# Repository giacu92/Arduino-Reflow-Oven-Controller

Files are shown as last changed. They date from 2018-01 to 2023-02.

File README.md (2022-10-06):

# GFE-Reflow-Oven-Controller v2
This repo contains all the files of my Arduino Zero (samd21) based Reflow Oven PID Controller for reflow smd soldering.

* Author: Giacomo Mammarella
* email: giacu92@gmail.com,

New

[Check the live version!](https://a360.co/3yNSDE0)

# For Arduino Nano (V1.1) refer to appropriate branch --> [v1.1](https://github.com/giacu92/Arduino-Reflow-Oven-Controller/tree/v1.1)

# File list:
* [Arduino files](https://github.com/giacu92/Reflow-Oven-Controller/tree/master/GFE_Reflow_Oven_Controller): The Arduino files source folder.
* [Processing file](https://github.com/giacu92/Reflow-Oven-Controller/tree/master/Processing/Reflow_oven_serial_controller): The Processing files source folder.
* [Prova.brd](https://github.com/giacu92/GFE-Reflow-Oven-Controller/blob/master/Prova.brd): Cadsoft Eagle 6.5 .brd file of my Reflow Oven Controller. 
* [Prova.sch](https://github.com/giacu92/GFE-Reflow-Oven-Controller/blob/master/Prova.sch): Cadsoft Eagle 6.5 .sch file of my Reflow Oven Controller.

# Mounting the board:
Get a fully assembled board [here](http://giacu92.bigcartel.com/product/reflow-oven-controller-board-v1-1) or etch it yourself. -- available soon

A newer version of the pcb featuring two thermocouple interface, +12V fan output (for cooling) is under development. It will fit the 16x2 LCD screen and mounts underneath it. Here's a sample rendering. Also a new pid autotuner function and MicroSD card interface for saving custom profiles are getting implemented.

New_top

This project is under continuous update (May 2022). Contact me for anything :)

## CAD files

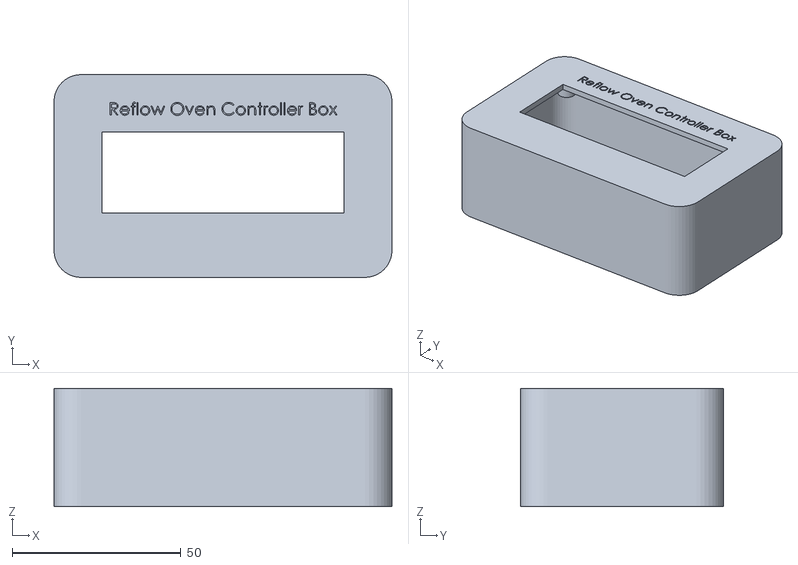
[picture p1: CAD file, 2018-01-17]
Serial Reflow Oven Controller Box.STL
100.0 x 60.0 x 35.0

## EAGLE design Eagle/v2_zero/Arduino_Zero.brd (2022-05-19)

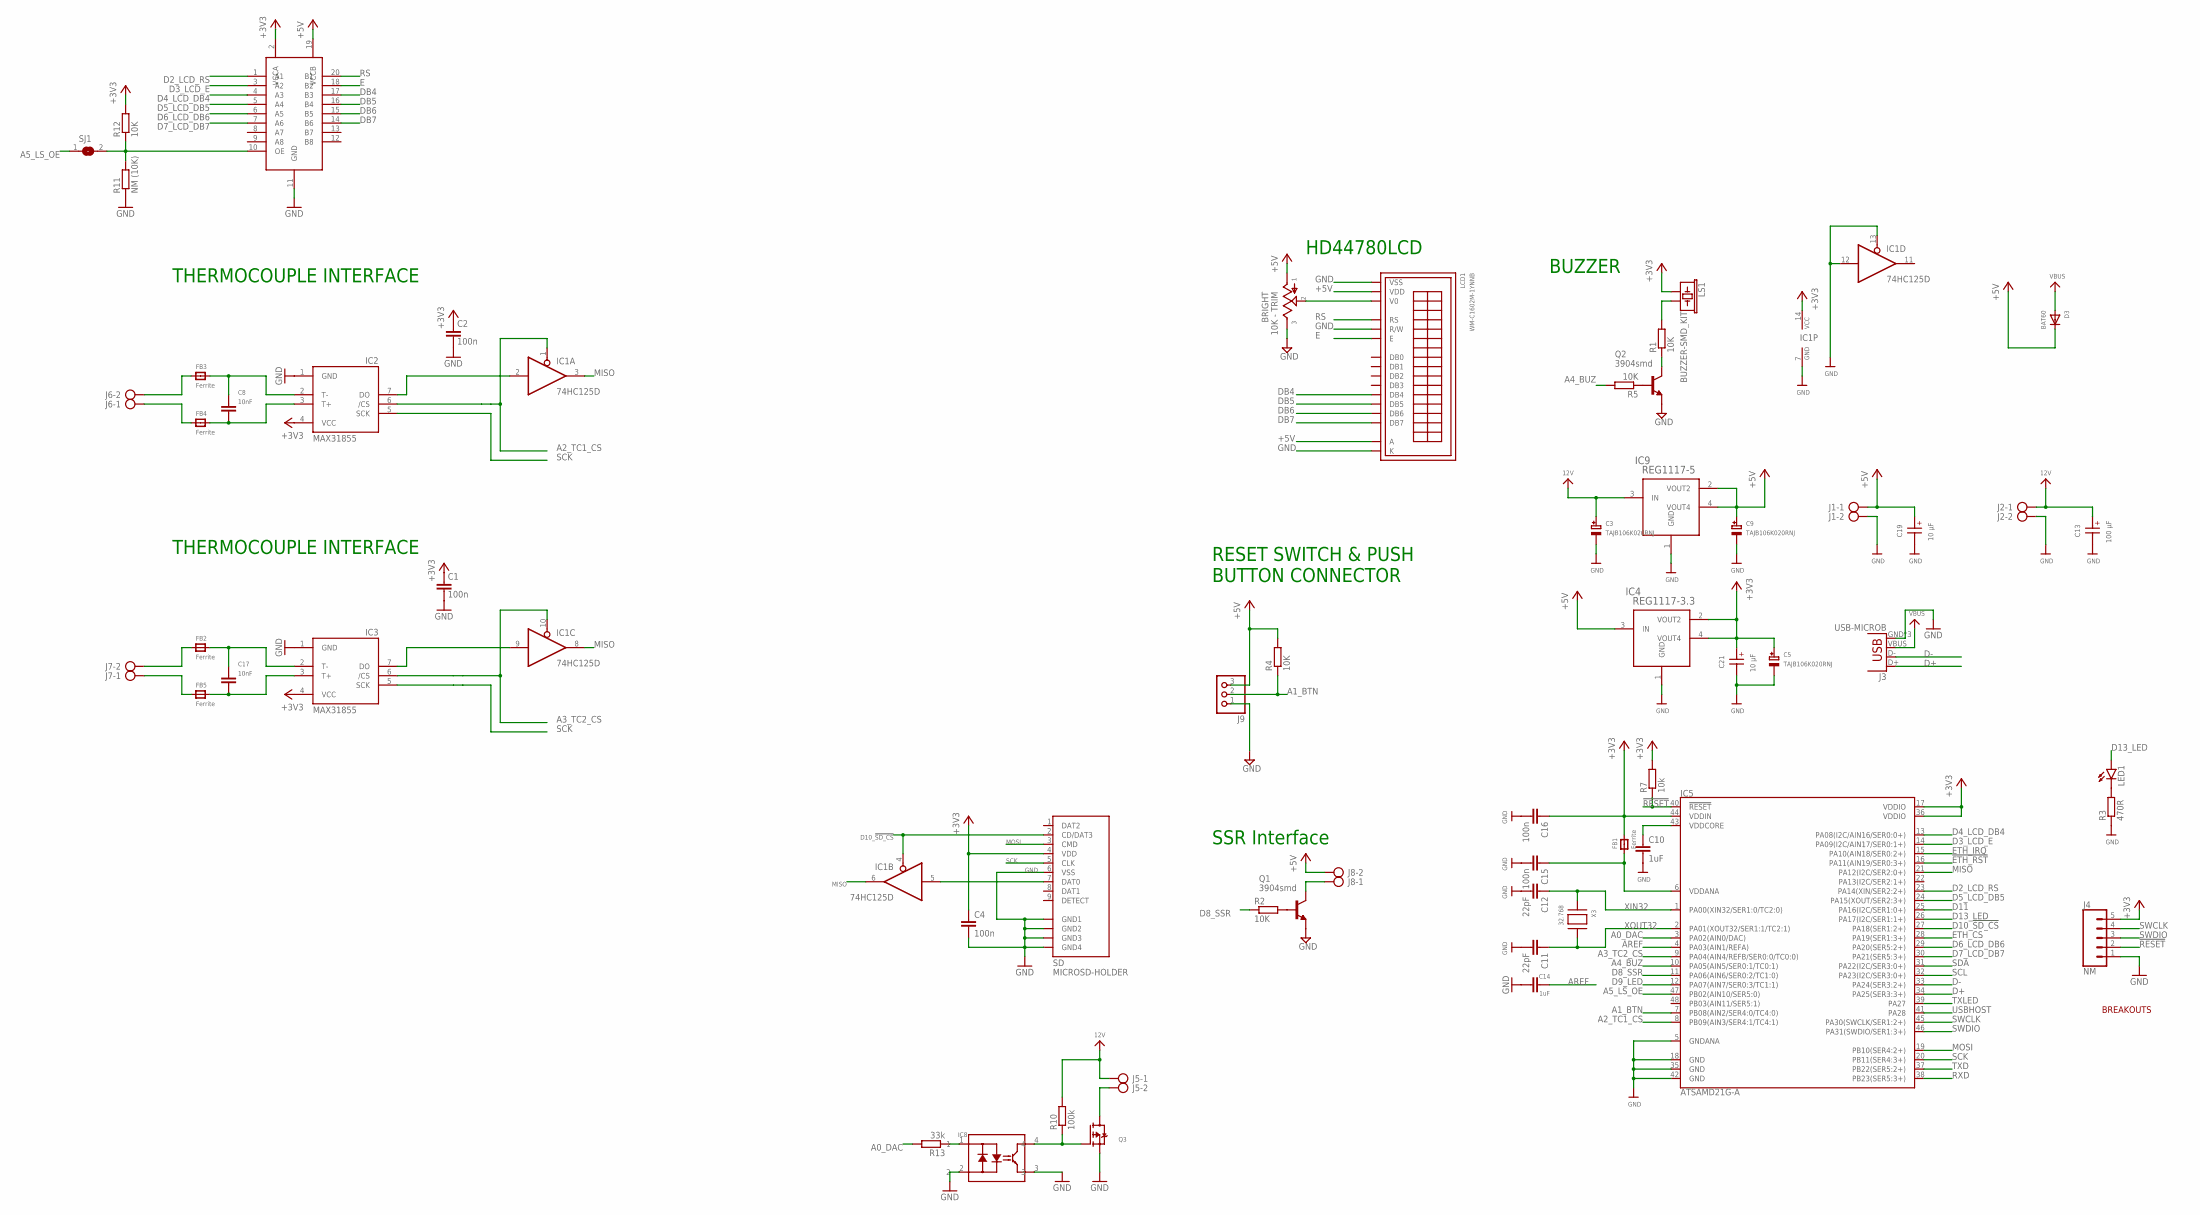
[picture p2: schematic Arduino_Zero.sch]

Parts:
BRIGHT: 10K - TRIM; B25P
C1, C2, C4, C15, C16: 100n; C0603K
C3, C5, C9: TAJB106K020RNJ; CAPMP3528X210N
C8, C17: 10nF; C0603K
C10, C14: 1uF; C0603K
C11, C12: 22pF; C0603K
C13: 100 µF; WCAP-ASLI_6.3X7.7(DXL)
C19, C21: 10 µF; WCAP-ASLI_4X5.5(DXL)
D3: BAT60; SOD323
FB1, FB2, FB3, FB4, FB5: Ferrite; BEADC3216X100N
IC1: 74HC125D; SO14
IC2, IC3: MAX31855; SO08
IC4: REG1117-3.3; DCY0004A_N
IC5: ATSAMD21G-A; TQFP-48
IC7: TXS0108E; TSSOP20
IC8: TLP283; SO4_TOS
IC9: REG1117-5; DCY0004A_N
J1, J2, J5, J6, J7, J8: AK500/2ASD; AK500/2
J3: USB-MICROB
J4: NM; 1X05_1.27MM
J9: PINHD-1X3; 1X03
LCD1: WM-C1602M-1YNNB; LCD_2
LED1: LEDCHIPLED_0805; CHIPLED_0805
LS1: BUZZER-SMD_KIT; BUZZER-CCV-KIT
Q1, Q2: 3904smd; SOT23-BEC
Q3: MOSFET-PWIDE; SOT23-WIDE
R1, R2, R4, R5, R12: 10K; R0603
R3: 470R; R0603
R7: 10k; R0603
R10: 100k; R0603
R11: NM (10K); R0603
R13: 33k; R0603
SD: MICROSD-HOLDER; MICROSD-HOLDER-ALIEX
SJ1: SJ
X3: 32.768; XTAL3215

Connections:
12V: C3.1 (+), C13.1 (+), IC9.3 (IN), J2.1, J5.1, R10.2
!ETH_RST: IC5.16 (PA11(AIN19/SER0:3+))
!RESET: IC5.40 (!RESET!), J4.2, R7.1
+3V3: C1.1, C2.1, C4.1, C5.1 (+), C16.1, C21.1 (+), FB1.2, IC1.14 (VCC), IC2.4 (VCC), IC3.4 (VCC), IC4.2 (VOUT2), IC4.4 (VOUT4), IC5.17 (VDDIO), IC5.36 (VDDIO), IC5.44 (VDDIN), IC7.2 (VCCA), J4.5, LS1.+ (1), R7.2, R12.2, SD.4 (VDD)
+5V: BRIGHT.1, C9.1 (+), C19.1 (+), D3.1 (C), IC4.3 (IN), IC7.19 (VCCB), IC9.2 (VOUT2), IC9.4 (VOUT4), J1.1, J8.2, J9.3, LCD1.2 (VDD), LCD1.15 (A), R4.2
A0_DAC: IC5.3 (PA02(AIN0/DAC)), R13.2
A1_BTN: IC5.7 (PB08(AIN2/SER4:0/TC4:0)), J9.2, R4.1
A2_TC1_CS: IC1.1 (OE), IC2.6 (/CS), IC5.8 (PB09(AIN3/SER4:1/TC4:1))
A3_TC2_CS: IC1.10 (OE), IC3.6 (/CS), IC5.9 (PA04(AIN4/REFB/SER0:0/TC0:0))
A4_BUZ: IC5.10 (PA05(AIN5/SER0:1/TC0:1)), R5.2
A5_LS_OE: IC5.47 (PB02(AIN10/SER5:0)), SJ1.1
AREF: C14.1, IC5.4 (PA03(AIN1/REFA))
D2_LCD_RS: IC5.23 (PA14(XIN/SER2:2+)), IC7.1 (A1)
D3_LCD_E: IC5.14 (PA09(I2C/AIN17/SER0:1+)), IC7.3 (A2)
D4_LCD_DB4: IC5.13 (PA08(I2C/AIN16/SER0:0+)), IC7.4 (A3)
D5_LCD_DB5: IC5.24 (PA15(XOUT/SER2:3+)), IC7.5 (A4)
D6_LCD_DB6: IC5.29 (PA20(SER5:2+)), IC7.6 (A5)
D7_LCD_DB7: IC5.30 (PA21(SER5:3+)), IC7.7 (A6)
D8_SSR: IC5.11 (PA06(AIN6/SER0:2/TC1:0)), R2.1
D9_LED: IC5.12 (PA07(AIN7/SER0:3/TC1:1))
D10_!SD_CS: IC1.4 (OE), IC5.27 (PA18(SER1:2+)), SD.2 (CD/DAT3)
D11: IC5.25 (PA16(I2C/SER1:0+))
D13_LED: IC5.26 (PA17(I2C/SER1:1+)), LED1.A
D+: IC5.34 (PA25(SER3:3+)), J3.D+
D-: IC5.33 (PA24(SER3:2+)), J3.D-
DB4: IC7.17 (B3), LCD1.11 (DB4)
DB5: IC7.16 (B4), LCD1.12 (DB5)
DB6: IC7.15 (B5), LCD1.13 (DB6)
DB7: IC7.14 (B6), LCD1.14 (DB7)
E: IC7.18 (B2), LCD1.6 (E)
ETH_CS: IC5.28 (PA19(SER1:3+))
ETH_IRQ: IC5.15 (PA10(AIN18/SER0:2+))
GND: BRIGHT.3, C1.2, C2.2, C3.2 (-), C4.2, C5.2 (-), C9.2 (-), C10.2, C11.2, C12.2, C13.2 (-), C14.2, C15.2, C16.2, C19.2 (-), C21.2 (-), IC1.7 (GND), IC1.12 (I), IC1.13 (OE), IC2.1 (GND), IC3.1 (GND), IC4.1 (GND), IC5.5 (GNDANA), IC5.18 (GND), IC5.35 (GND), IC5.42 (GND), IC7.11 (GND), IC8.2, IC8.3, IC9.1 (GND), J1.2, J2.2, J3.GND, J3.MT1 (GND), J3.MT2 (GND), J4.1, J9.1, LCD1.1 (VSS), LCD1.5 (R/W), LCD1.16 (K), Q1.E, Q2.E, Q3.2 (S), R3.1, R11.1, SD.6 (VSS), SD.P$1 (GND1), SD.P$2 (GND2), SD.P$3 (GND3), SD.P$4 (GND4)
MISO: IC1.3 (O), IC1.6 (O), IC1.8 (O), IC5.21 (PA12(I2C/SER2:0+))
MOSI: IC5.19 (PB10(SER4:2+)), SD.3 (CMD)
unnamed: Q2.B, R5.1
unnamed: J8.1, Q1.C
unnamed: Q1.B, R2.2
unnamed: LS1.- (2), R1.2
unnamed: BRIGHT.2, LCD1.3 (V0)
unnamed: LED1.C, R3.2
unnamed: IC1.2 (I), IC2.7 (DO)
unnamed: IC1.5 (I), SD.7 (DAT0)
unnamed: J5.2, Q3.3 (D)
unnamed: IC7.10 (OE), R11.2, R12.1, SJ1.2
unnamed: FB2.1, J7.2
unnamed: IC8.1, R13.1
unnamed: C17.1, FB2.2, IC3.2 (T-)
unnamed: IC8.4, Q3.1 (G), R10.1
unnamed: FB5.1, J7.1
unnamed: C17.2, FB5.2, IC3.3 (T+)
unnamed: Q2.C, R1.1
unnamed: IC1.9 (I), IC3.7 (DO)
unnamed: FB3.1, J6.2
unnamed: C8.1, FB3.2, IC2.2 (T-)
unnamed: FB4.1, J6.1
unnamed: C8.2, FB4.2, IC2.3 (T+)
unnamed: C15.1, FB1.1, IC5.6 (VDDANA)
unnamed: C10.1, IC5.43 (VDDCORE)
RS: IC7.20 (B1), LCD1.4 (RS)
RXD: IC5.38 (PB23(SER5:3+))
SCK: IC2.5 (SCK), IC3.5 (SCK), IC5.20 (PB11(SER4:3+)), SD.5 (CLK)
SCL: IC5.32 (PA23(I2C/SER3:0+))
SDA: IC5.31 (PA22(I2C/SER3:0+))
SWCLK: IC5.45 (PA30(SWCLK/SER1:2+)), J4.4
SWDIO: IC5.46 (PA31(SWDIO/SER1:3+)), J4.3
TXD: IC5.37 (PB22(SER5:2+))
TXLED: IC5.39 (PA27)
USBHOST: IC5.41 (PA28)
VBUS: D3.2 (A), J3.VBUS
XIN32: C12.1, IC5.1 (PA00(XIN32/SER1:0/TC2:0)), X3.P$1
XOUT32: C11.1, IC5.2 (PA01(XOUT32/SER1:1/TC2:1)), X3.P$2

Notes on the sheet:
SSR Interface
BUZZER
HD44780LCD
RESET SWITCH & PUSH BUTTON CONNECTOR
THERMOCOUPLE INTERFACE
BREAKOUTS

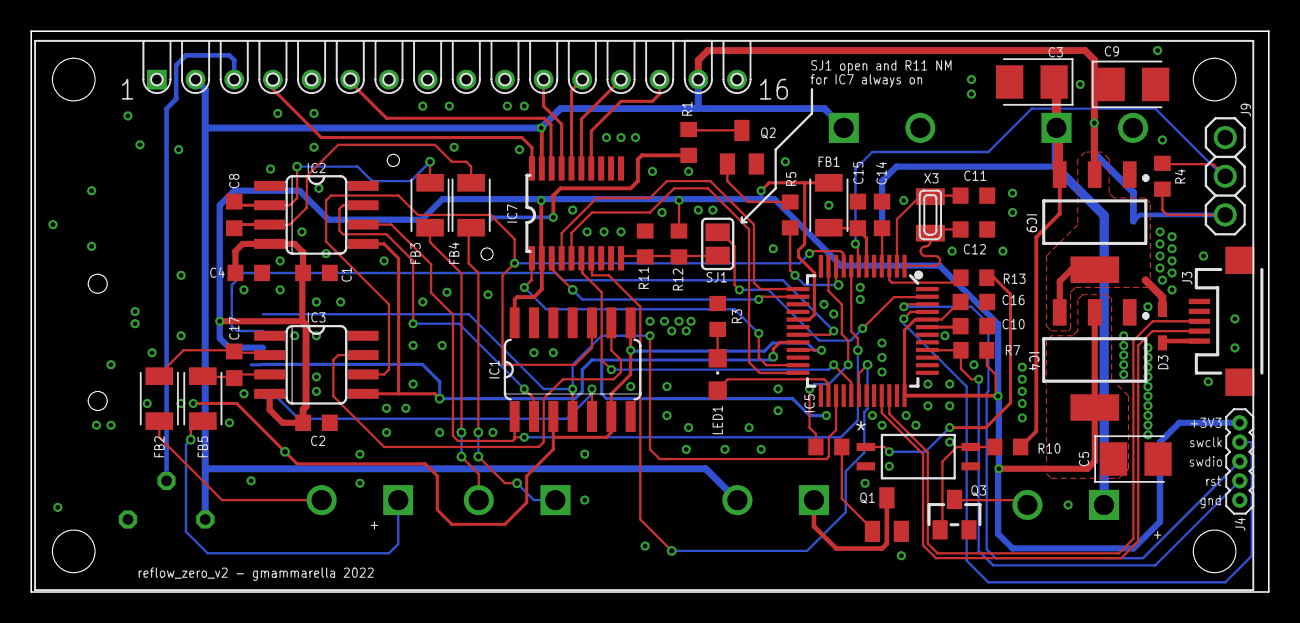
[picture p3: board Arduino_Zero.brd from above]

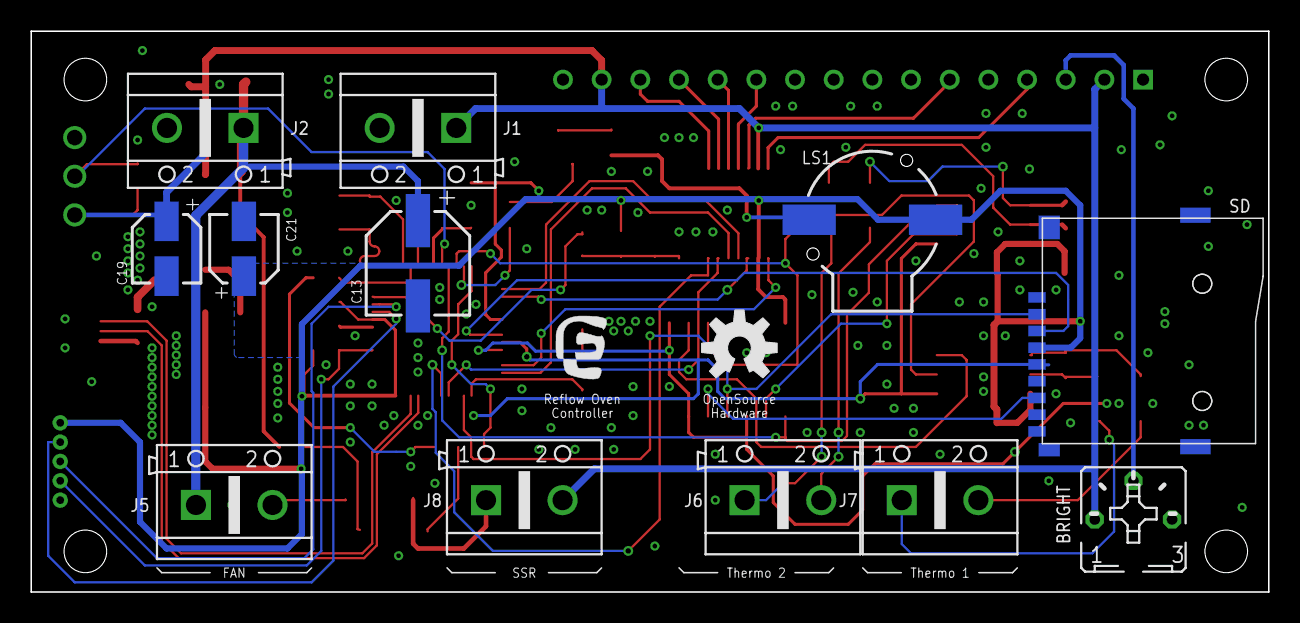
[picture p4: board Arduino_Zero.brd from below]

Board: 2 copper layers, 81.3 x 36.8 mm, 62 parts (14 on the bottom side), 61 nets.

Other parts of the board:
U$1: LOGO_PICCOLO
U$2: OSHW-LOGO-M

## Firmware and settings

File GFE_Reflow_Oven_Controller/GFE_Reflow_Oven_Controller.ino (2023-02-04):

/*
   Revision  Description
   ========  ===========
   1.1       Arduino Nano v3 for GFE Hand Made Reflow Oven Controller board v1.1
             - Compiled for Arduino Nano.
             - Display changed to 16x2 Hitachi HD44780 Compatible.
             - added data output to diplay temperature vs time.
             - added possibility to choose between lead free of leaded solder paste profiles.

   1.2       Arduino Nano v3 for GFE Hand Made Reflow Oven Controller board v1.2
             - Added sounds.
             - Added temperature self check. The process self stops if unable to drive the oven.

   2.0       Arduino Zero (reflowZero board)
             - Added second thermocouple (#ifdef USE_TC2)
             - To be Added: error code register
                e.g.:
                    15  14  13  12  11  10  09  08  07  06  05  04  03  02  01  00             
                    -   -   tc2 tc1 ip   -   -   -   -   -   -   -   -   -   -   -

                    tc1/2: connected tc
                    ip: ip address acquired 
    
   Temperature (Degree Celcius)                 Magic Happens Here!
   245-|                                               x  x
       |                                            x        x
       |                                         x              x
       |                                      x                    x
   200-|                                   x                          x
       |                              x    |                          |   x
       |                         x         |                          |       x
       |                    x              |                          |
   150-|               x                   |                          |
       |             x |                   |                          |
       |           x   |                   |                          |
       |         x     |                   |                          |
       |       x       |                   |                          |
       |     x         |                   |                          |
       |   x           |                   |                          |
   30 -| x             |                   |                          |
       |<  60 - 90 s  >|<    90 - 120 s   >|<       90 - 120 s       >|
       | Preheat Stage |   Soaking Stage   |       Reflow Stage       | Cool
    0  |_ _ _ _ _ _ _ _|_ _ _ _ _ _ _ _ _ _|_ _ _ _ _ _ _ _ _ _ _ _ _ _ _ _ _ _
                                                                  Time (Seconds)
*/

// ***** INCLUDES *****
#include <SPI.h>
#include <LiquidCrystal.h>
#include "Adafruit_MAX31855.h"
#include "PID_v1.h"

//#define USE_LCD_KEYPAD_SHIELD
#define VERSION_2_ZERO
#define FINE_CONTROL
#define NOPRIOR_HEAT

#ifdef VERSION_2_ZERO
  #define Serial SerialUSB
  #undef USE_LCD_KEYPAD_SHIELD
  #define USE_TC2
  #define USE_ETHERNET
  #define USE_SERVO
#endif

#ifdef USE_SERVO
  #include <Servo.h>
  Servo servoMotor;
#endif

//#define AUTOTUNE_BETA

// ***** TCP IP CONFIG *****
#ifdef USE_ETHERNET
  #include "Ethernet.h"
  #include <EthernetUdp.h>
  #include <ArduinoOTA.h>
  #include <FastCRC.h>
  byte mac[] = {0xDC, 0xAE, 0x2E, 0xEE, 0xFE, 0xE0};
  IPAddress ip(192, 168, 0, 209);
  unsigned int localPort = 40292;

  EthernetUDP udp;
  FastCRC16 CRC16;
#endif

// ***** AUTOTUNE *****
#ifdef AUTOTUNE_BETA
  #include <PID_AutoTune_v0.h>
#endif

// ***** CONSTANTS *****
#define TEMPERATURE_ROOM 50

#define TEMPERATURE_COOL_MIN 100
#define SENSOR_SAMPLING_TIME 1000
#define SOAK_TEMPERATURE_STEP 2
#define SOAK_MICRO_PERIOD 1000 /*7000*/
#define DEBOUNCE_PERIOD_MIN 50


// ***** PID PARAMETERS *****
// Pre-Heating:
#define PID_KP_PREHEAT 60    //100
#define PID_KI_PREHEAT 0.05    //0.025
#define PID_KD_PREHEAT 50    //20
// Soaking:
#define PID_KP_SOAK 100  //300
#define PID_KI_SOAK 0.05       //0.05
#define PID_KD_SOAK 100          //250
// Reflowing:
#define PID_KP_REFLOW  300     //300
#define PID_KI_REFLOW  0.10    //0.05
#define PID_KD_REFLOW  350    //350

#ifdef USE_SERVO
  #define PID_KP_COOL 20
  #define PID_KI_COOL 0.5
  #define PID_KD_COOL 50
#endif

// Sample time:
#define PID_SAMPLE_TIME 250

// Notes:
#define  note_c     261 //Hz
#define  note_cd    277 //Hz
#define  note_d     294 //Hz
#define  note_e     330 //Hz
#define  note_f     349 //Hz
#define  note_fg    370 //Hz
#define  note_g     392 //Hz
#define  note_ga    415 //Hz
#define  note_a     440 //Hz
#define  note_ab    466 //Hz
#define  note_b     494 //Hz
#define  note_C     523 //Hz

// ***** TYPE DEFINITIONS *****
typedef enum REFLOW_STATE
{
  REFLOW_STATE_IDLE,
  REFLOW_STATE_PRIOR,
  REFLOW_STATE_PREHEAT,
  REFLOW_STATE_SOAK,
  REFLOW_STATE_REFLOW,
  REFLOW_STATE_COOL,
  REFLOW_STATE_COMPLETE,
  REFLOW_STATE_TOO_HOT,
  REFLOW_STATE_ERROR,
  REFLOW_STATE_TUNING_PH
}
reflowState_t;

typedef enum REFLOW_STATUS
{
  REFLOW_STATUS_OFF,
  REFLOW_STATUS_ON
}
reflowStatus_t;

// ***** LCD MESSAGES *****
const char* lcdMessagesReflowStatus[] = {
  "Ready",
  "Prior",
  "Preheat",
  "Soak",
  "Reflow",
  "Cool",
  "Complete",
  "Wait,hot",
  "Error",
  "Tuning"
};

// ***** DEGREE SYMBOL FOR LCD *****
unsigned char degree[8]  = { 140, 146, 146, 140, 128, 128, 128, 128 };

// ***** PIN ASSIGNMENT *****
#if defined(USE_LCD_KEYPAD_SHIELD)
  #define btnRIGHT  0
  #define btnUP     1
  #define btnDOWN   2
  #define btnLEFT   3
  #define btnSELECT 4
  #define btnNONE   5
  #define ssrPin             2//6
  #define spi_miso           11//5
  #define tc_cs              12//4
  #define spi_sck            13//3
  #define lcdRsPin           8//9
  #define lcdEPin            9//10
  #define lcdD4Pin           4//A5
  #define lcdD5Pin           5//A4
  #define lcdD6Pin           6//A3
  #define lcdD7Pin           7//A2
  #define ledRedPin          A1//8
  #define buzzerPin          A2//7
  #define switchPin          A0
  #define lcdBrightnessPin   10
#elif defined(VERSION_2_ZERO)
  #define ssrPin             8
  #define spi_miso           (22u)
  #define tc_cs              PIN_A2 //TBC
  #define tc2_cs             PIN_A3 //TBC
  #define spi_sck            (24u)
  #define lcdRsPin           2
  #define lcdEPin            3
  #define lcdD4Pin           4
  #define lcdD5Pin           5
  #define lcdD6Pin           6
  #define lcdD7Pin           7
  #define ledRedPin          13 
  #define buzzerPin          PIN_A4 //TBC
  #define switchPin          PIN_A1
  #define ethRstPin          0
#else
  #define ssrPin             6
  #define spi_miso           5
  #define tc_cs              4
  #define spi_sck            3
  #define lcdRsPin           9
  #define lcdEPin            10
  #define lcdD4Pin           A5
  #define lcdD5Pin           A4
  #define lcdD6Pin           A3
  #define lcdD7Pin           A2
  #define ledRedPin          8
  #define buzzerPin          7
  #define switchPin          A0
#endif
int data = 0;
//uint8_t data = 0;
const char leftByte = 'd';
const char rightByte = ':';
const char stopByte = '&';

// ***** PID CONTROL VARIABLES *****
double setpoint;
double input;
double output;
double kp = PID_KP_PREHEAT;
double ki = PID_KI_PREHEAT;
double kd = PID_KD_PREHEAT;
const int windowSize = 500; /*2000;*/
unsigned long windowStartTime;
unsigned long nextCheck;
unsigned long nextRead;
unsigned long timerSoak;
unsigned long buzzerPeriod;

#ifdef USE_SERVO
  double position;
#endif

#ifdef AUTOTUNE_BETA
  // ***** PID AUTOTUNE VARIABLES *****
  byte ATuneModeRemember = 2;
  #define aTuneStep        1000
  #define aTuneNoise       1
  #define aTuneStartValue 1000;
  unsigned int aTuneLookBack = 2;
#endif

// Reflow oven controller state machine state variable
reflowState_t reflowState;
// Reflow oven controller status
reflowStatus_t reflowStatus;
// Switch debounce timer
long lastDebounceTime;
// Seconds timer
long timerSeconds = 0;
long timeToCheck  = 20;
int checkTemperature = 0;

bool endOfPrevProcess = false;

int TEMPERATURE_PREHEAT_MIN = 40;
int TEMPERATURE_SOAK_MIN = 145;
int TEMPERATURE_SOAK_MAX = 180;
int TEMPERATURE_REFLOW_MAX = 230;

#ifdef FINE_CONTROL
  int PH_TARGET_DURATION = 60;
  double PH_TEMPERATURE_STEP_D = (TEMPERATURE_SOAK_MIN - TEMPERATURE_PREHEAT_MIN) * (double)SOAK_MICRO_PERIOD / (double)PH_TARGET_DURATION / 1000;

  int REFLOW_RU_TARGET_DURATION = 40; //Reflow Ramp-Up target duration
  double REFLOW_TEMPERATURE_STEP_D = (TEMPERATURE_REFLOW_MAX - TEMPERATURE_SOAK_MAX) * (double)SOAK_MICRO_PERIOD / (double)REFLOW_RU_TARGET_DURATION / 1000;
#endif

int SOAK_TARGET_DURATION = 90;
double SOAK_TEMPERATURE_STEP_D = (TEMPERATURE_SOAK_MAX - TEMPERATURE_SOAK_MIN) * (double)SOAK_MICRO_PERIOD / (double)SOAK_TARGET_DURATION / 1000;

String type = "";

//Simulator
bool isSimulation = false;

// ***** DEFINING OBJECTS *****
// Specify PID control interface
PID reflowOvenPID(&input, &output, &setpoint, kp, ki, kd, DIRECT);
#ifdef AUTOTUNE_BETA
  PID_ATune aTune(&input, &output);
#endif
#ifdef USE_SERVO
  PID coolingPID(&input, &position, &setpoint, kp, ki, kd, DIRECT);
#endif

// Specify LCD interface
LiquidCrystal lcd(lcdRsPin, lcdEPin, lcdD4Pin, lcdD5Pin, lcdD6Pin, lcdD7Pin);


#ifndef VERSION_2_ZERO
  Adafruit_MAX31855 thermocouple(spi_sck, tc_cs, spi_miso);
#else
  Adafruit_MAX31855 thermocouple(tc_cs);
#endif

#ifdef USE_TC2
  Adafruit_MAX31855 tc2(tc2_cs);
#endif

void setup()
{
  // SSR pin initialization to ensure reflow oven is off
  pinMode(ssrPin, OUTPUT);
  digitalWrite(ssrPin, LOW);

  // Buzzer pin initialization to ensure annoying buzzer is off
  digitalWrite(buzzerPin, LOW);
  pinMode(buzzerPin, OUTPUT);

  // LED pins initialization and turn on upon start-up (active low)
  pinMode(ledRedPin, OUTPUT);
  digitalWrite(ledRedPin, HIGH);

  // Tell the PID to range between 0 and the full window size
  reflowOvenPID.SetOutputLimits(0, windowSize);
  reflowOvenPID.SetSampleTime(PID_SAMPLE_TIME);

  // Serial communication at 57600 bps
  Serial.begin(57600);
  /*
  #ifdef VERSION_2_ZERO
    while(!SerialUSB);
  #endif
  */

  // V2.0b -- Zero only
  #if defined (VERSION_2_ZERO)
    analogReadResolution(12);
    pinMode(10, OUTPUT);
    pinMode(ethRstPin, OUTPUT);
    digitalWrite(ethRstPin, LOW);
    delay(1);

    digitalWrite(10, HIGH);
    digitalWrite(PIN_A2, HIGH);
    digitalWrite(PIN_A3, HIGH);
    digitalWrite(ethRstPin, HIGH);
    delay(2);
  #endif

  // V2.0b -- Servo cooling
  #if defined USE_SERVO
    servoMotor.attach(PIN_A0);

    coolingPID.SetOutputLimits(0, 255);
    coolingPID.SetSampleTime(PID_SAMPLE_TIME);

    servoMotor.write(0);
  #endif
  
  // Start-up splash
  lcd.begin(16, 2);
  lcd.createChar(0, degree);
  lcd.clear();
  lcd.print("GFE Hand Made");
  lcd.setCursor(0, 1);
  lcd.print("Reflow Oven 2.0b");

  //pinMode(13, OUTPUT);
 // digitalWrite(13, LOW);

  // Ethernet communication initialization
#ifdef USE_ETHERNET
  Ethernet.init(12);
  delay(1000);
  Ethernet.begin(mac, ip);

  if (Ethernet.hardwareStatus() == EthernetNoHardware)  Serial.println("WARNING: Ethernet shield was not found.  Sorry, can't run without hardware. :(");
  else if (Ethernet.linkStatus() == LinkOFF)            Serial.println("Ethernet cable is not connected.");
  else                                                  Serial.println("INFO: Ethernet OK");

  ArduinoOTA.begin(Ethernet.localIP(), "Arduino", "password", InternalStorage);

  udp.begin(localPort);
  delay(1);
#endif

  // Turn off LED (active low)
  digitalWrite(ledRedPin, LOW);

  // Welcome sound
  soundStart();
  lcd.clear();

  // Initialize time keeping variable
  nextCheck = millis();
  // Initialize thermocouple reading variable
  nextRead = millis();
  reflowState = REFLOW_STATE_IDLE;

#ifdef USE_LCD_KEYPAD_SHIELD
  pinMode(lcdBrightnessPin, OUTPUT);
  analogWrite(lcdBrightnessPin, 125);
#endif

#ifdef FINE_CONTROL
  Serial.println("PH_TEMPERATURE_STEP_D = " + (String)PH_TEMPERATURE_STEP_D);
  Serial.println("SOAK_TEMPERATURE_STEP_D = " + (String)SOAK_TEMPERATURE_STEP_D);
  Serial.println("REFLOW_TEMPERATURE_STEP_D = " + (String)REFLOW_TEMPERATURE_STEP_D);
#endif
}

void loop()
{
  ArduinoOTA.poll();
  // Current time
  unsigned long now;

  // Time to read thermocouple?
  if (millis() > nextRead)
  {
    // Read thermocouple next sampling period
    nextRead += SENSOR_SAMPLING_TIME;
    
    if (!isSimulation)
    {
      // Read current temperature
      input = getTemp();
      /*input = thermocouple.readCelsius();
      #ifdef USE_TC2
        double in_tc2 = tc2.readCelsius();
        if (isnan(input))    { input = in_tc2; }
        else if (!isnan(in_tc2))   { input = (input + in_tc2) / 2.0; }   //average value of the two tc
      #endif
      Serial.println("TC input = " + (String)input);*/
    }
    else
    {
      //Serial.println("Simulator input = " + (String)input);
    }

    // If thermocouple problem detected
    if (isnan(input))
    {
      // Illegal operation
      reflowState = REFLOW_STATE_ERROR;
      reflowStatus = REFLOW_STATUS_OFF;
    }
  }

  if (millis() > nextCheck)
  {
    // Check input in the next seconds
    nextCheck += 1000;
    // If reflow process is on going
    if (reflowStatus == REFLOW_STATUS_ON && reflowState != REFLOW_STATE_PRIOR)
    {
      // Toggle red LED as system heart beat
      digitalWrite(ledRedPin, !(digitalRead(ledRedPin)));
      // Increase seconds timer for reflow curve analysis
      timerSeconds++;

      // Send temperature and time stamp to serial as csv standard
      String dataToSend = "(" + (String)timerSeconds + "," + (String)setpoint + "," + (String)input + "," + (String)output + ")";
      //char* buf = (char*) malloc(sizeof(char) * dataToSend.length() + 1);

     // dataToSend.toCharArray(buf, dataToSend.length() + 1);

#ifndef USE_ETHERNET
      char* buf = (char*) malloc(sizeof(char) * dataToSend.length() + 1);

      dataToSend.toCharArray(buf, dataToSend.length() + 1);
      //Serial.println(buf);
      

      // Freeing the memory;
      free(buf);
#else
      udp.beginPacket(udp.remoteIP(), udp.remotePort());
      udp.write(dataToSend.c_str());
      udp.endPacket();
#endif

      
    }
    else
    {
      // Turn off red LED
      digitalWrite(ledRedPin, HIGH);
    }

    // Clear LCD
    lcd.clear();
    lcd.setCursor(11, 1);
    if (reflowStatus == REFLOW_STATUS_ON)
    {
      lcd.print(type);
      // Print Stop Button
      lcd.setCursor(0, 1);
      lcd.print("stop");
      lcd.setCursor(6, 1);
      lcd.print(timerSeconds);
      lcd.print(" s");
    }
    else
    {
      lcd.print("start");
      lcd.setCursor(0, 1);
#ifdef USE_LCD_KEYPAD_SHIELD
      lcd.print("menu");
#else
      lcd.print("prSet");
#endif
    }

    // Print current system state
    lcd.setCursor(0, 0);
    lcd.print(lcdMessagesReflowStatus[reflowState]);
    // Move the cursor to the 2 line
    lcd.setCursor(9, 0);

    // If currently in error state
    if (reflowState == REFLOW_STATE_ERROR)
    {
      // No thermocouple wire connected
      lcd.print("TC Err");
    }
    else
    {
      // Print current temperature
      lcd.print(input);

#if ARDUINO >= 100
      // Print degree Celsius symbol
      lcd.write((uint8_t)0);
#else
      // Print degree Celsius symbol
      lcd.print(0, BYTE);
#endif
      lcd.print("C ");
    }
  }

  // Reflow oven controller state machine
  switch (reflowState)
  {
    case REFLOW_STATE_IDLE:
      // If oven temperature is still above room temperature
      if (input >= TEMPERATURE_ROOM)
      {
        reflowState = REFLOW_STATE_TOO_HOT;
      }

      else
      {
        // If switch is pressed to start reflow process
        char dataIn[100] = {""};
#ifndef USE_ETHERNET
        if (Serial.available() > 0)
        {
          //Leggo la stringa in arrivo dalla seriale.
          //char dataIn[100] = {""};
          Serial.readBytes(dataIn, 100);
          String receivedString(dataIn);
          data = dataIn[0];
          Serial.println("SERIAL - Received string: " + receivedString);
#else
        if (udp.parsePacket())
        {
          String receivedString = udp.readString();

          if (receivedString.equals("GFE_reflowOven_uThrBro?!"))
          {
            Serial.println("UDP - Received Discovery String: " + receivedString);
            String asReply = "helloFrom_GFEreflowOven__2.0b__";
            for (int i=0; i < 4; i++)
            {
              asReply += String(ip[i], DEC);
              if (i < 3)
              {
                asReply += ".";
              }
            }
            asReply += "__" + String(localPort, DEC) + "__";

            uint8_t buf[100];
            asReply.getBytes(buf, sizeof(asReply));
            uint16_t crc[2]= {CRC16.ccitt(buf, sizeof(buf))};

            udp.beginPacket(udp.remoteIP(), udp.remotePort());
            udp.write(asReply.c_str());
            udp.endPacket();
          }
#endif
          //Serial.println("1 dataIn[0] = " + data);

          int iniPac = receivedString.indexOf('(');
          int endPac = receivedString.indexOf(')');

          //se ci sono i caratteri di inizio e fine pacchetto è un messaggio,
          //altrimenti ho ricevuto solo un dato da inserire in data.
          if (iniPac != -1 && endPac != -1 && endPac - iniPac > 1)
          {
            Serial.println("UDP - INFO: received message packet " + receivedString);
            String packetIn = receivedString;
            packetIn = packetIn.substring(iniPac + 1, endPac); //tolgo le parentesi

            // Simulator support
            if (receivedString.indexOf("[S],") >= 0)
            {
              //Serial.println("flag");
              isSimulation = true;
              // Override temps
              input = packetIn.substring(4, packetIn.length()).toDouble();
            }
            else
            {

#if defined FINE_CONTROL
              int lastVal = 7;
#else
              int lastVal = 4;
#endif
              int valoriIn[lastVal] = {-100};
              for (int i = 0; packetIn.indexOf(',') != -1; i++)
              {
                int index = packetIn.indexOf(',');
                valoriIn[i] = packetIn.substring(0, index).toInt();
                packetIn = packetIn.substring(index + 1, packetIn.length());
              }
              valoriIn[lastVal-1] = packetIn.substring(0,packetIn.length()).toInt();

              TEMPERATURE_SOAK_MIN =    valoriIn[0];
              TEMPERATURE_SOAK_MAX =    valoriIn[1];
              TEMPERATURE_REFLOW_MAX =  valoriIn[2];
              //TEMPERATURE_COOL_MIN =    valoriIn[3];

#if defined FINE_CONTROL
              PH_TARGET_DURATION        = valoriIn[4];
              SOAK_TARGET_DURATION      = valoriIn[5];
              REFLOW_RU_TARGET_DURATION = valoriIn[6];  

              PH_TEMPERATURE_STEP_D = (TEMPERATURE_SOAK_MIN - TEMPERATURE_PREHEAT_MIN) * (double)SOAK_MICRO_PERIOD / (double)PH_TARGET_DURATION / 1000;
              REFLOW_TEMPERATURE_STEP_D = (TEMPERATURE_REFLOW_MAX - TEMPERATURE_SOAK_MAX) * (double)SOAK_MICRO_PERIOD / (double)REFLOW_RU_TARGET_DURATION / 1000;
#endif
              SOAK_TEMPERATURE_STEP_D = (TEMPERATURE_SOAK_MAX - TEMPERATURE_SOAK_MIN) * (double)SOAK_MICRO_PERIOD / (double)SOAK_TARGET_DURATION / 1000;

              Serial.println("PH_TEMPERATURE_STEP_D = " + (String)PH_TEMPERATURE_STEP_D);
              Serial.println("SOAK_TEMPERATURE_STEP_D = " + (String)SOAK_TEMPERATURE_STEP_D);
              Serial.println("REFLOW_TEMPERATURE_STEP_D = " + (String)REFLOW_TEMPERATURE_STEP_D);

              type = " [C]";
              sendProfile();
            }
          }

          else
          {
#ifndef USE_ETHERNET
            data = dataIn[0];
#else
            Serial.println("UDP - Received string: " + receivedString);
            data = receivedString.charAt(0);
#endif
            receivedString = "";

            //Serial.println("2 dataIn[0] = " + data);
          }
        }

        if (analogRead(switchPin) < 30 || data == rightByte)
        {
          data = 0;
#ifdef USE_LCD_KEYPAD_SHIELD
          delay(200);
#endif

          if (TEMPERATURE_SOAK_MIN < 50)
            profileSet();

          //Saving data for heating check:
          //checkTemperature = thermocouple.readCelsius();
          checkTemperature = getTemp();
/*
#ifdef USE_TC2
          double in_tc2 = tc2.readCelsius();
          if (!isnan(in_tc2))   { checkTemperature = (checkTemperature + in_tc2) / 2.0; }   //average value of the two tc
#endif
*/
          timeToCheck = 20;
          // Inizio il ciclo, mando i miei dati via seriale per settare il grafico.
          sendProfile();

          //while(input < 40) //PRIOR HEATING
          //{
          //  digitalWrite(ssrPin, HIGH);
          //}

          // Ora mando l'header per il file CSV
          Serial.println("Time Setpoint Input Output");
          // Intialize seconds timer for serial debug information
          nextCheck = millis();
          timerSeconds = 0;
          // Initialize PID control window starting time
          windowStartTime = millis();
#ifndef FINE_CONTROL
            // Ramp up to minimum soaking temperature
            setpoint = TEMPERATURE_SOAK_MIN;
#else
            setpoint = TEMPERATURE_PREHEAT_MIN + PH_TEMPERATURE_STEP_D;  
#endif
          Serial.print("setpoint: ");
          Serial.println(setpoint);

          // Turn the PID on
          reflowOvenPID.SetMode(AUTOMATIC);
          // Proceed to preheat stage
          reflowOvenPID.SetTunings(PID_KP_PREHEAT, PID_KI_PREHEAT, PID_KD_PREHEAT);
#if defined ETH_DEBUG
          reflowState = REFLOW_STATE_PREHEAT;
#elif defined NOPRIOR_HEAT
          reflowState = REFLOW_STATE_PREHEAT; 
#else
          reflowState = REFLOW_STATE_PRIOR; //prior heating to heat up the quartz elements
#endif
#ifdef USE_SERVO
          servoMotor.write(0);
#endif
        }
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

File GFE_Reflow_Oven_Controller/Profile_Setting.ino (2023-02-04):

void menu_page()
{
  lcd.clear();
  lcd.setCursor(6,0);
  lcd.print("MENU");
  lcd.setCursor(0,1);
  lcd.print("prSet");
  lcd.setCursor(11,1);
  lcd.print("build");

  int val = 1024;
  while(val > 1000 && data == 0) // need a pull-up resistor (10KΩ)
  {
    val = analogRead(switchPin);
  }
  
  if (val < 30 || data == rightByte) //right button pressed => build profile
  {
    #ifdef USE_LCD_KEYPAD_SHIELD
      delay(200);
      profileBuild();
    #endif
  }
    
  else if (val >= 30 || data == leftByte)
  {    
    while(analogRead(switchPin) < 1000) { delay(100); } // debounce
    delay(100);
    profileSet();
  }

  data = 0;
}

void profileSet()
{
  lcd.clear();
  lcd.setCursor(0,0);
  lcd.print("Lead-free paste?");
  lcd.setCursor(0,1);
  lcd.print("yes");
  lcd.setCursor(14, 1);
  lcd.print("no");

  int val = 1024;

  while(val > 1000 && data == 0) // need a pull-up resistor (10KΩ)
  {
    val = analogRead(switchPin);
#ifndef USE_ETHERNET
    if(Serial.available() > 0)
    {
      //digitalWrite(13,HIGH);
      data = Serial.read();
      delay(100);
    }
    delay(100);
    //digitalWrite(13,LOW);
#else
    if (udp.parsePacket())
    {
      String receivedString = udp.readString();
      data = receivedString.charAt(0);
    }
#endif
    //Serial.println(reflowStatus);
  }

  if (val < 30 || data == rightByte) //right button pressed => LEADED_PROFILE
  {
    #ifdef USE_LCD_KEYPAD_SHIELD
      delay(200);
    #endif
    TEMPERATURE_SOAK_MIN = 150;
    TEMPERATURE_SOAK_MAX = 177;
    TEMPERATURE_REFLOW_MAX = 210;
    type = "  [L]";
  }
    
  else if (val >= 30 || data == leftByte)
  {
    #ifdef USE_LCD_KEYPAD_SHIELD
      delay(200);
    #endif
    TEMPERATURE_SOAK_MIN = 150;
    TEMPERATURE_SOAK_MAX = 200;
    TEMPERATURE_REFLOW_MAX = 250;
    type = " [LF]";
  }

  SOAK_TEMPERATURE_STEP_D = (TEMPERATURE_SOAK_MAX - TEMPERATURE_SOAK_MIN) * (double)SOAK_MICRO_PERIOD / (double)SOAK_TARGET_DURATION / 1000;

  data = 0;
  delay(1000);
  
  sendProfile();
}

void sendProfile()
{
#ifdef FINE_CONTROL
  String dataToSend =
    "(" + type + ","
        + TEMPERATURE_SOAK_MIN      + ","
        + TEMPERATURE_SOAK_MAX      + ","
        + TEMPERATURE_REFLOW_MAX    + ","
        + PH_TARGET_DURATION        + ","
        + SOAK_TARGET_DURATION      + ","
        + REFLOW_RU_TARGET_DURATION + ")";
#else
  String dataToSend =
    "(" + type + ","
        + TEMPERATURE_SOAK_MIN   + ","
        + TEMPERATURE_SOAK_MAX   + ","
        + TEMPERATURE_REFLOW_MAX + ")";
#endif

  char* buf = (char*)malloc(sizeof(char)*dataToSend.length()+1);
#ifndef USE_ETHERNET
  dataToSend.toCharArray(buf, dataToSend.length()+1);
  Serial.println(buf);
  
#else
  //client.print(dataToSend);
  udp.beginPacket(udp.remoteIP(), udp.remotePort());
  udp.write(dataToSend.c_str());
  udp.endPacket();
#endif
  free(buf);
  dataToSend = "";

  lcd.clear();
  lcd.setCursor(0,0);
  lcd.print("T Preheat=");
  lcd.setCursor(11, 0);
  lcd.print(TEMPERATURE_SOAK_MIN);
  lcd.write((uint8_t)0);
  lcd.print("C");
  lcd.setCursor(0,1);
  lcd.print("T Soak=");
  lcd.setCursor(11, 1);
  lcd.print(TEMPERATURE_SOAK_MAX);
  lcd.write((uint8_t)0);
  lcd.print("C");
  delay(1000);
  lcd.clear();
  lcd.setCursor(0,0);
  lcd.print("T Refl=");
  lcd.setCursor(11, 0);
  lcd.print(TEMPERATURE_REFLOW_MAX);
  lcd.write((uint8_t)0);
  lcd.print("C");
  lcd.setCursor(0,1);
  lcd.print("T Cool=");
  lcd.setCursor(11, 1);
  lcd.print(TEMPERATURE_COOL_MIN);
  lcd.write((uint8_t)0);
  lcd.print("C");
  delay(1000);
}

void soundStart() //Roppoppò
{
  tone(buzzerPin, note_g);
  delay(400);
  noTone(buzzerPin);
  delay(50);
  tone(buzzerPin, note_b);
  delay(200);
  noTone(buzzerPin);
  delay(50);
  tone(buzzerPin, note_d*2);
  delay(200);
  noTone(buzzerPin);
  delay(50);
  tone(buzzerPin, note_g);
  delay(400);
  noTone(buzzerPin);
  delay(50);
  tone(buzzerPin, note_b);
  delay(200);
  noTone(buzzerPin);
  delay(50);
  tone(buzzerPin, note_d*2);
  delay(200);
  noTone(buzzerPin);
  delay(50);
  tone(buzzerPin, note_g);
  delay(400);
  noTone(buzzerPin);
}

void soundComplete() //Indiana Jones
{
  tone(buzzerPin, note_cd);
  delay(300);
  noTone(buzzerPin);
  delay(100);
  tone(buzzerPin, note_cd);
  delay(100);
  noTone(buzzerPin);
  delay(50);
  tone(buzzerPin, note_ga);
  delay(900);
  noTone(buzzerPin);
  delay(50);
  tone(buzzerPin, note_ab);
  delay(120);
  noTone(buzzerPin);
  delay(50);
  tone(buzzerPin, note_ga);
  delay(120);
  noTone(buzzerPin);
  delay(50);
  tone(buzzerPin, note_fg);
  delay(120);
  noTone(buzzerPin);
  delay(50);
  tone(buzzerPin, note_ga);
  delay(800);
  noTone(buzzerPin);
}
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

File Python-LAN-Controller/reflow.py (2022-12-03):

import tkinter as tk
from tkinter import ttk
import serial, threading, leds, os, re
import matplotlib.pyplot as plt
from serial.tools.list_ports import comports
import sv_ttk

class App(tk.Tk):
    _serialport = ""
    _baudrate = 115200
    _portlist = []
    _isConnected = False
    _serialCon = None
    _threadTXled = None
    _baudrate_list = [4800, 9600, 19200, 28800, 57600, 115200]

    _startX = 40
    _startY = 320
    _stopX = 738
    _stopY = 40
    _stepX = int((_stopX-50-_startX)/12)
    _stepY = int((_startY-_stopY+10)/6 )

    TEMPERATURE_SOAK_MIN   = 150
    TEMPERATURE_SOAK_MAX   = 177
    TEMPERATURE_REFLOW_MAX = 230
    TEMPERATURE_COOLDOWN   = 100

    DURATION_PH             = 75
    DURATION_SOAK           = 105
    DURATION_REFLOW_RAMPUP  = 60


    
    def __init__(self):
        super().__init__()
        self.protocol("WM_DELETE_WINDOW", self.on_closing)
        
        self._portlist = serial.tools.list_ports.comports()
        
        ## Configure the root window
        self.title("Reflow oven serial controller")
        self.geometry("800x600")

        self.resizable(0, 0)
        #self.columnconfigure(0, weight=1)
        self.columnconfigure(1, weight=1)

        #self.rowconfigure(0, weight=1)
        #self.rowconfigure(1, weight=2)

        #self.call("source", "azure.tcl")
        #self.call("set_theme", "light")
        sv_ttk.set_theme("light")

        self.setup_widgets()

        ## Manage serial
        self.manageSerial()
    
    def setup_widgets(self):

        ## Serial Port Frame
        self.cb_frame = ttk.LabelFrame(self, text="Serial port config", padding=(10,10))
        #self.cb_frame.grid(row=0, column=0, padx=(20, 10), pady=(20, 10), sticky="nsew")
        self.cb_frame.grid(row=0, column=0, padx=(20, 20), pady=(10, 10), sticky="nsew")

        #   combo-box - COM list
        self.combobox = ttk.Combobox(self.cb_frame, textvariable="serial_port", width=50, height=10, justify='left')
        self.combobox['values'] = [ p.device for p in self._portlist ]
        self.combobox.set(self._portlist[0].device)
        #self.combobox.place(x=10, y=12)
        self.combobox.grid(row=0, column=0, padx=5, pady=10, sticky="nsew")
        self.combobox.bind("<<ComboboxSelected>>", self.on_select)

        #   combo-box - baudrate
        self.cb_baudrate = ttk.Combobox(self.cb_frame, textvariable="baudvar", width=50, height=10, justify='left')
        self.cb_baudrate['values'] = self._baudrate_list
        self.cb_baudrate.set(self._baudrate_list[1])
        self.cb_baudrate.grid(row=1, column=0, padx=5, pady=10, sticky="nsew")
        #self.cb_baudrate.place(x=10, y=32)
        #self.cb_baudrate.bind("<<ComboboxSelected>>", self.on_select)

        #   button - refresh
        self.btn_refresh = ttk.Button(self.cb_frame, text="Refresh", width=10)
        self.btn_refresh['command'] = self.refresh_clicked
        self.btn_refresh.grid(row=0, column=1, padx=5, pady=10, sticky="nsew")
        #self.btn_refresh.place(x=380, y=8)
        
        #   button - connect
        self.btn_connect = ttk.Button(self.cb_frame, text="Connect", width=10)
        self.btn_connect['command'] = self.connect_clicked
        self.btn_connect.grid(row=1, column=1, padx=5, pady=10, sticky="nsew")
        #self.btn_connect.place(x=380, y=32)

        #   label - selected_port
        self.label = ttk.Label(self.cb_frame, text=self._portlist[self.combobox.current()].description)
        self.label.grid(row=2, column=0, padx=5, pady=10, sticky="nsew")
        #self.label.place(x=10,y=60)


        ## Led Frame
        self.leds_frame = ttk.LabelFrame(self, text="Controls", padding=(10,10))
        self.leds_frame.grid(row=0, column=1, padx=(20, 20), pady=(10, 10), sticky="nsew")
        
        ## Canvas
        #   led canvas
        self.led_canvas = tk.Canvas(self.leds_frame, width=150, height=45)
        self.led_canvas.grid(row=0, column=1, padx=5, pady=10, sticky="nsew")
        #self.led_canvas.place(x=600,y=00)   #grid(row=3,column=0, columnspan=5)

        #   leds
        #self.ledCon = self.canvas.create_oval(10, 20, 25, 35, fill='#e6e6c8')   #   #e6e6c8 - yellow off
        #self.ledTX  = self.canvas.create_oval(40, 20, 55, 35, fill='#a5d4b6')   #   #b4ebc8 - green off
        #self.ledRX  = self.canvas.create_oval(70, 20, 85, 35, fill='#d18a8a')   #   #d18a8a - red off

        self.ledCon = leds.led(self.led_canvas, 20,  20, 15, '#00ff00', "CON", offColor="#ff0000")
        self.ledTX  = leds.led(self.led_canvas, 70,  20, 15, 'YELLOW', "TX",  offColor="#f5dca9")
        self.ledRX  = leds.led(self.led_canvas, 120, 20, 15, 'GREEN', "RX")

        ## Threads
        ##self.ledTX_thread = threading.Timer(1, self.tx_blink, None) #target=self.tx_blink
        ##self.ledTX_thread.start()
        self._threadTXled = leds.Blink

        #self.tx_blink()
        #self.rx_blink()

        #   graph canvas
        self.graph_canvas = tk.Canvas(width=775, height=480, bg="white")
        self.graph_canvas.grid(row=1, column=0, columnspan=2, padx=(20, 20), pady=(10, 10), sticky="nsew")
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

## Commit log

2016-02-13 Files
    First add of a batch of file for my Arduino Nano SMD Reflow Oven
    Controller
    [Prova.brd, Prova.sch]
2016-02-15 minor bug fixes
    [Prova.brd, Prova.sch]
2016-03-29 Arduino sketch
    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
    [GFE_Reflow_Oven_Controller.ino, Profile_Setting.ino]
2017-07-05 Arduino code update and bug fix
    [GFE_Reflow_Oven_Controller.ino, Profile_Setting.ino]
2017-08-30 Bug fix on temperatures
2018-01-02 bug fix and update
    [GFE_Reflow_Oven_Controller.ino, Profile_Setting.ino]
2018-01-03 Added self temperature check
2018-01-04 Added PID autotuner
    PID autotuner still need more adjustments
2018-01-04 Bug fix and macOS application ready
    [aggiornaInterfaccia.pde, gui.pde]
2018-01-17 Bug fix
    A stupid commas screwing up it all
    [GFE_Reflow_Oven_Controller.ino]
2018-01-17 STL file for 3D printed box
    [Serial Reflow Oven Controller Box.STL]
2018-02-26 Bug fix
    Fixes a bug when the “profileSet” got hit and didn’t give choice for
    the setting
    [GFE_Reflow_Oven_Controller.ino, Profile_Setting.ino, aggiornaInterfaccia.pde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]
2018-03-11 Bug Fix
    Fixed a bug that may have caused false positive SSR failures check
    [GFE_Reflow_Oven_Controller.ino]
2018-03-11 Bug Fix
    Fixed a bug that may have caused false positive in SSR power check
    [GFE_Reflow_Oven_Controller.ino]
2018-11-09 update
    Some mods added like the prior heating, to heat up elements before the cycle starts
2022-05-11 created v2
    commit
    [Arduino_Zero.brd, Arduino_Zero.sch]
2022-05-12 update 3d packages
    small updates
    [Arduino_Zero.brd, Arduino_Zero.sch]
2022-05-12 schematic update
    [Arduino_Zero.brd, Arduino_Zero.sch]
2022-05-12 schematic optimization
    [Arduino_Zero.brd, Arduino_Zero.sch]
2022-05-19 add eth eagle version
    [Arduino_Zero.brd, Arduino_Zero.sch]
2022-11-21 added oven simulator and servo pid for cooling
2022-12-08 fix ethernet
    Ethernet now working :)
    [GFE_Reflow_Oven_Controller.ino, Profile_Setting.ino]

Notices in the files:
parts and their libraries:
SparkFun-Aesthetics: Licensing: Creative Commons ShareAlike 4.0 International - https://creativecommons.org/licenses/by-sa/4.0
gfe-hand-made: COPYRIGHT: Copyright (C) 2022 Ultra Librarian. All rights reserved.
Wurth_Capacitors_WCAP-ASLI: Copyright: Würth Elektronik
